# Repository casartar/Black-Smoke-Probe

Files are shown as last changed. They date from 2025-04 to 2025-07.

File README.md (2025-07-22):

# Black Smoke Probe

## Einleitung
Die Black Smoke Probe ist eine Open Source Hardware, die kompatibel ist zur Black Magic Probe v2.1e.

Ich habe den letzten öffentlich zugänglichen [Schaltplan](https://black-magic.org/_downloads/5a984c502435264dc19bc5e08c8b55cd/bmpm_v2_1e_schematic.pdf) genommen und die Micro-USB durch eine USB-C Buchse ersetzt. 

Da die Platine leicht von Hand zu bestücken sein sollte, ist das Layout single sided und einige Bauteile als auch die Diemensions der Platine größer gewählt als beim Original. Diesen Maßnahmen ist die UART zum Opfer gefallen und ist nur noch als Testpoints auf der Bottom Seite verfügbar (Ohne Level-Shifter). 

## Original Firmware
[https://github.com/blackmagic-debug/blackmagic](https://github.com/blackmagic-debug/blackmagic)

## iBOM
[ibom.html](https://html-preview.github.io/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)

## Flashen

### Flashen des Bootloaders
```
st-flash write blackmagic_native_bootloader.bin 0x08000000
```

### Flashen der Applikation
```
dfu-util -d 1d50:6018,:6017 -s 0x08002000:leave -D blackmagic_native_firmware.bin
```

## Testen

[https://github.com/casartar/BlackPillUniversalTester](https://github.com/casartar/BlackPillUniversalTester)

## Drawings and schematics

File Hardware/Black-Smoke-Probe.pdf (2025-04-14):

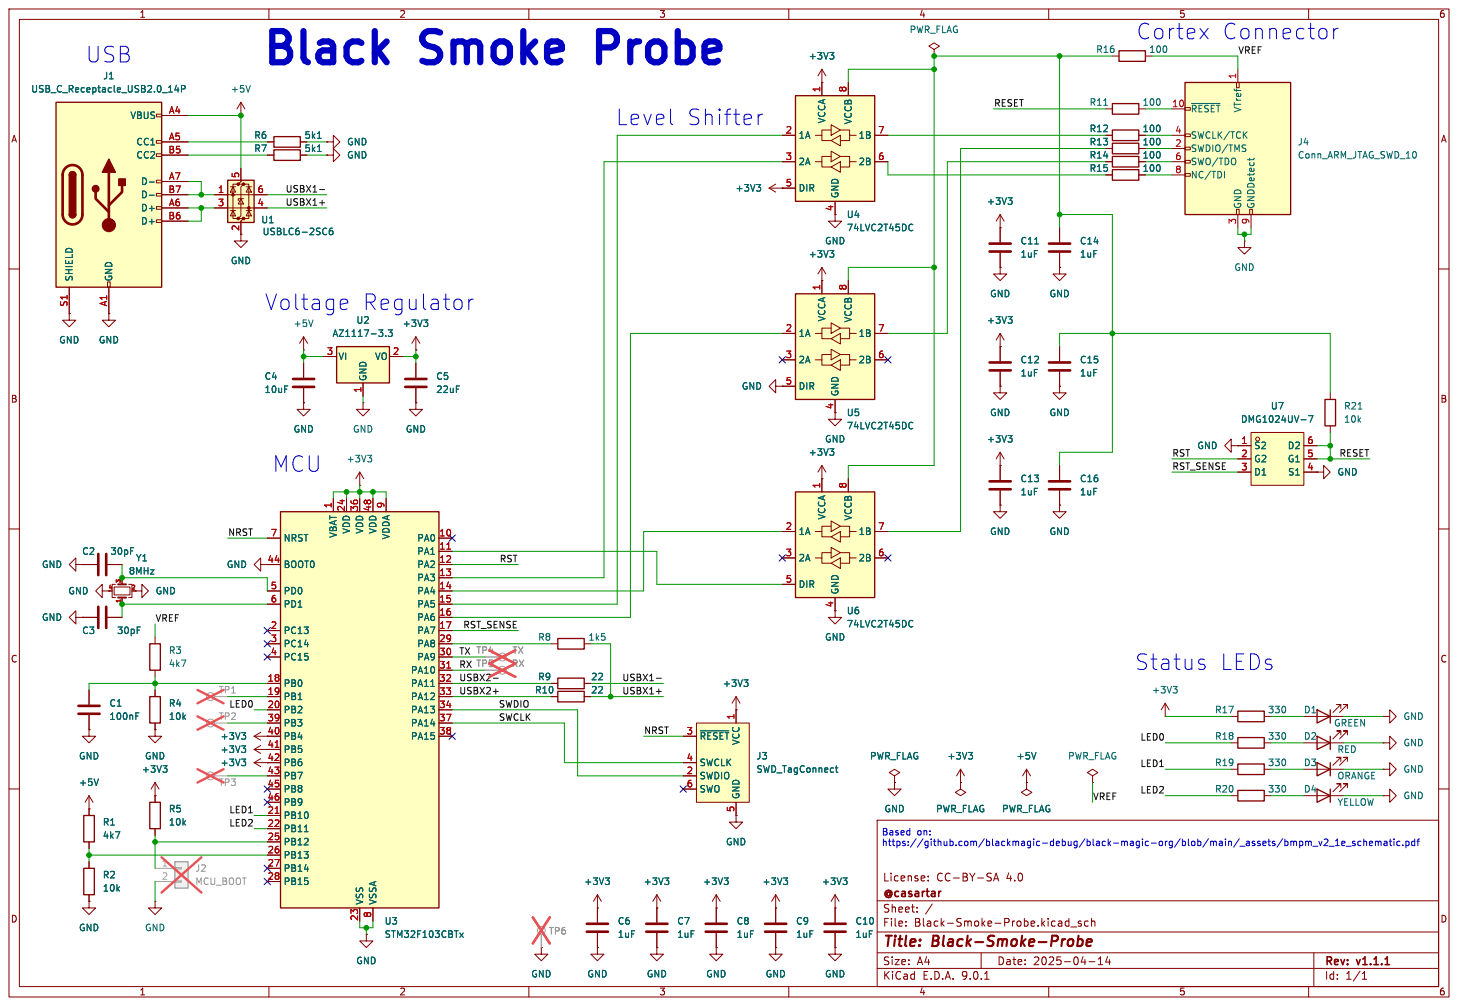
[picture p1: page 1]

3 ~{RESET} 10 SWCLK/TCK 4 SWDIO/TMS 2 SWO/TDO 6 NC/TDI 8

1 VDD 24 VDD 36 VSS 23 VDD 48 VSSA

5 ~{RESET} 3 SWCLK 4 SWDIO 2 SWO 6 R10 22 TP5 RX R9 22 TP4 TX GND

5 ~{RESET} 3 SWCLK 4 SWDIO 2 SWO 6

Based on: https://github.com/blackmagic-debug/black-magic-org/blob/main/_assets/bmpm_v2_1e_schematic.pdf

Id: 1/1 Title: Black-Smoke-Probe

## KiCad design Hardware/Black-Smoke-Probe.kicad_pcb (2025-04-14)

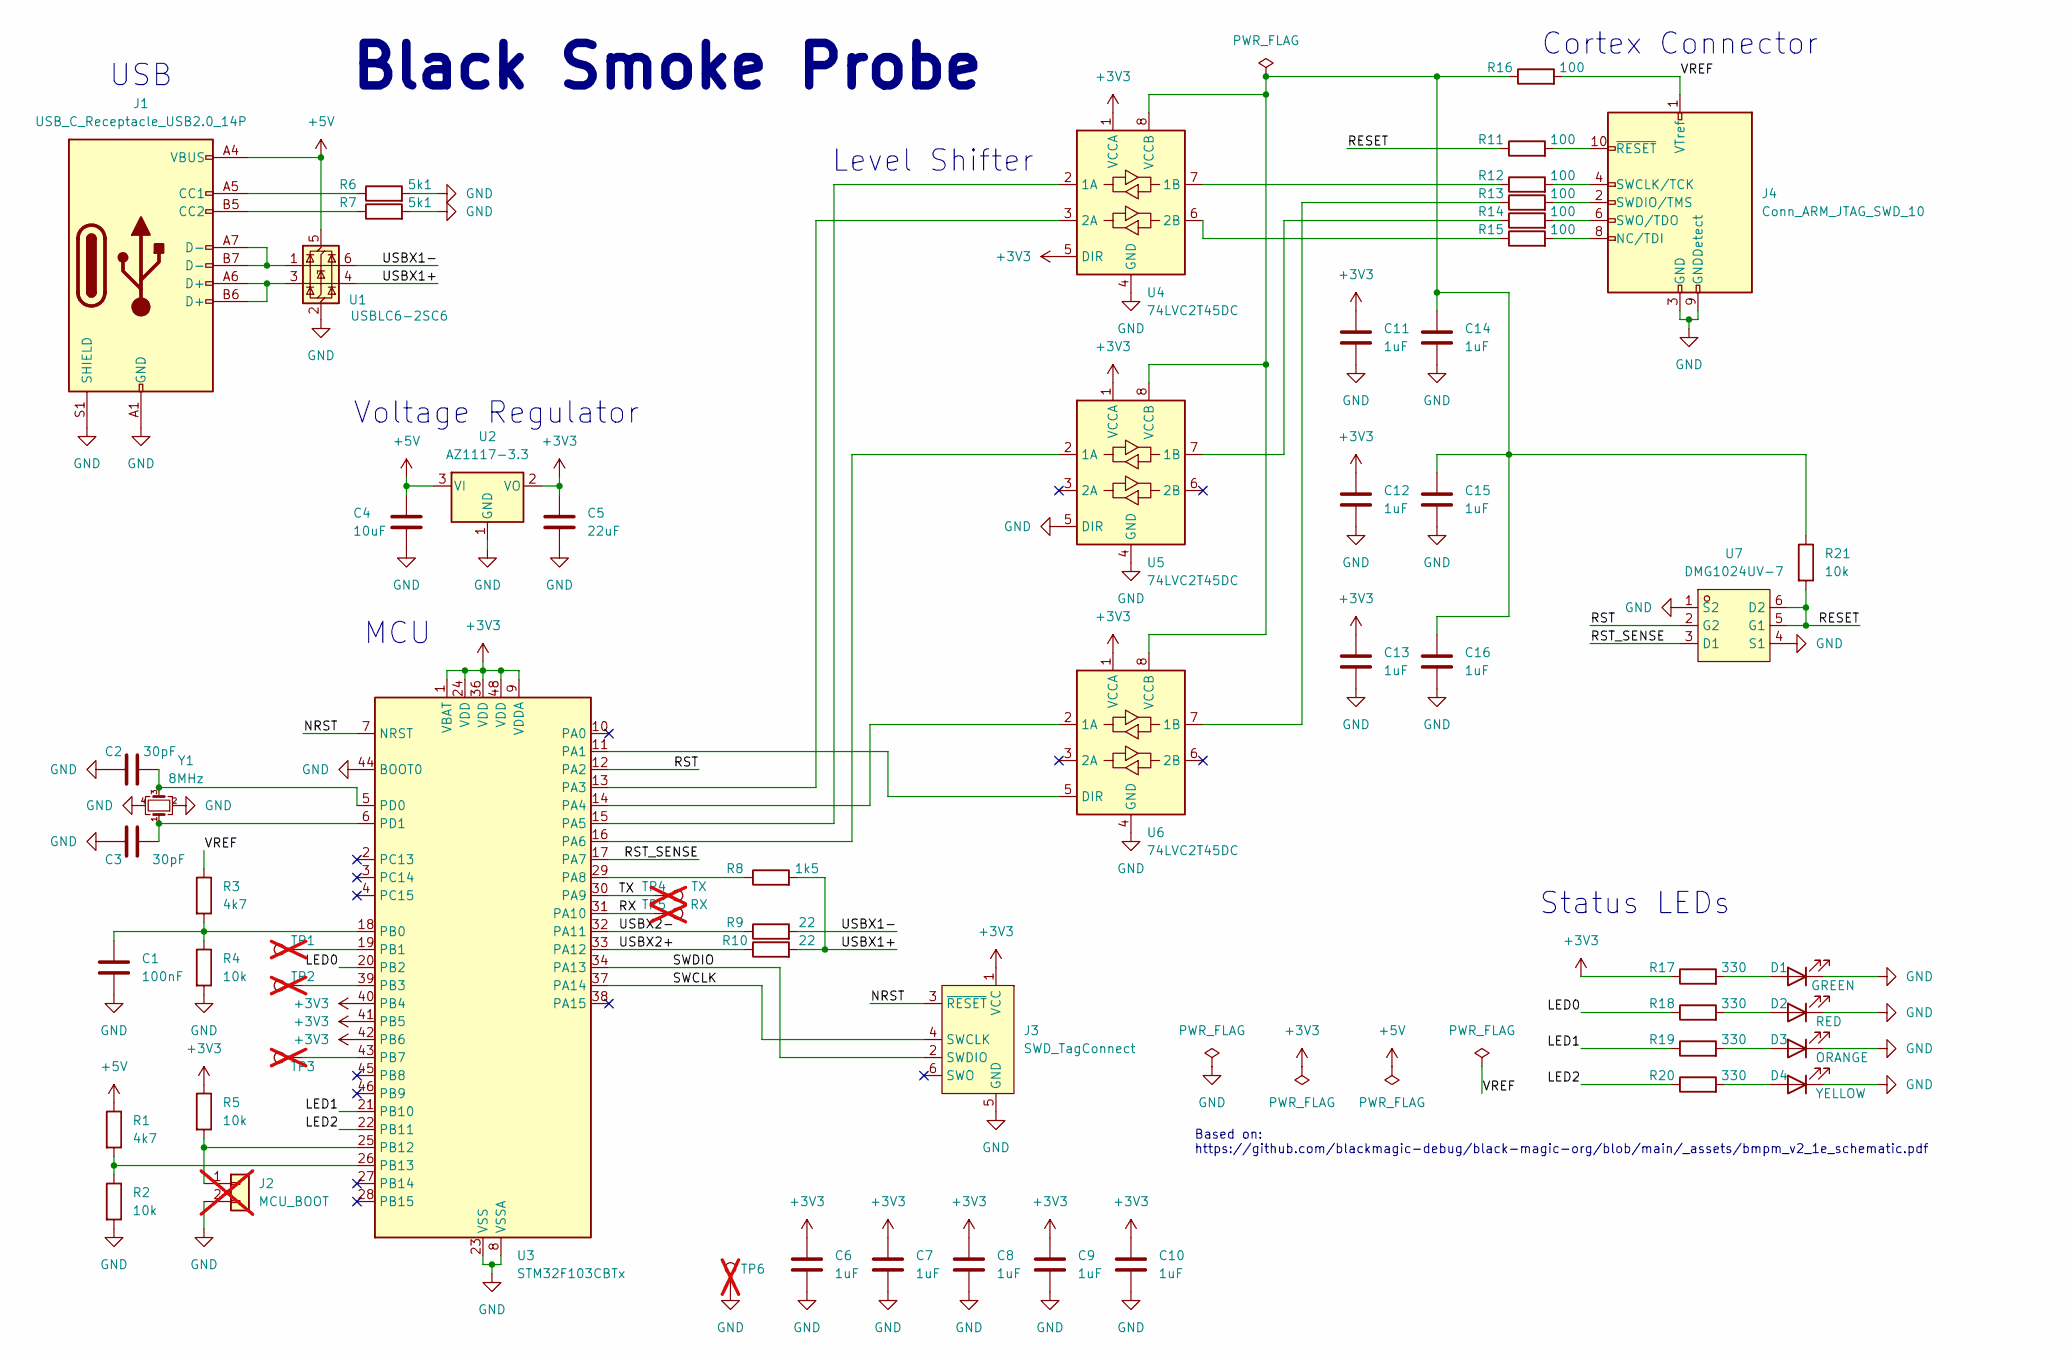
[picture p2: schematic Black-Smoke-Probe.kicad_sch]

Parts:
C1: 100nF; C_0603_1608Metric; LCSC Part C14663
C2, C3: 30pF; C_0603_1608Metric; LCSC Part C1658
C4: 10uF; C_0603_1608Metric; LCSC Part C19702
C5: 22uF; C_0603_1608Metric; LCSC Part C86295
C6, C7, C8, C9, C10, C11, C12, C13, C14, C15, C16: 1uF; C_0603_1608Metric; LCSC Part C15849
D1: GREEN; LED_0603_1608Metric; LCSC Part C12065
D2: RED; LED_0603_1608Metric; LCSC Part C157741
D3: ORANGE; LED_0603_1608Metric; LCSC Part C157740
D4: YELLOW; LED_0603_1608Metric; LCSC Part C160477
J1: USB_C_Receptacle_USB2.0_14P; USB_C_Receptacle_HRO_TYPE-C-31-M-12; LCSC Part C165948
J2: MCU_BOOT; PinHeader_1x02_P2.54mm_Vertical; not fitted
J3: SWD_TagConnect; Tag-Connect_TC2030-IDC-NL_2x03_P1.27mm_Vertical
J4: Conn_ARM_JTAG_SWD_10; PinHeader_2x05_P1.27mm_Vertical_SMD; LCSC Part C42372555
R1, R3: 4k7; R_0603_1608Metric; LCSC Part C105428
R2, R4, R5, R21: 10k; R_0603_1608Metric; LCSC Part C98220
R6, R7: 5k1; R_0603_1608Metric; LCSC Part C105580
R8: 1k5; R_0603_1608Metric; LCSC Part C22843
R9, R10: 22; R_0603_1608Metric; LCSC Part C1203
R11, R12, R13, R14, R15, R16: 100; R_0603_1608Metric; LCSC Part C105588
R17, R18, R19, R20: 330; R_0603_1608Metric; LCSC Part C105881
TP1, TP2, TP3, TP6: TestPoint; TestPoint_Pad_D1.0mm; not fitted
TP4: TX; TestPoint_Pad_D1.0mm; not fitted
TP5: RX; TestPoint_Pad_D1.0mm; not fitted
U1: USBLC6-2SC6; SOT-23-6; LCSC Part C2827654
U2: AZ1117-3.3; SOT-89-3; LCSC Part C460428
U3: STM32F103CBTx; LQFP-48_7x7mm_P0.5mm; LCSC Part C8304
U4, U5, U6: 74LVC2T45DC; VSSOP-8_2.3x2mm_P0.5mm; LCSC Part C15741
U7: DMG1024UV-7; SOT-563-6_L1.6-W1.2-P0.5-LS1.6-BL; LCSC Part C2759893
Y1: 8MHz; Crystal_SMD_3225-4Pin_3.2x2.5mm; LCSC Part C2682775

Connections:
+3V3: C5.1, C6.1, C7.1, C8.1, C9.1, C10.1, C11.1, C12.1, C13.1, J3.1 (VCC), R5.1, R17.1, U2.2 (VO), U3.1 (VBAT), U3.9 (VDDA), U3.24 (VDD), U3.36 (VDD), U3.40 (PB4), U3.41 (PB5), U3.42 (PB6), U3.48 (VDD), U4.1 (VCCA), U4.5 (DIR), U5.1 (VCCA), U6.1 (VCCA)
+5V: C4.1, J1.A4 (VBUS), J1.A9 (VBUS), J1.B4 (VBUS), J1.B9 (VBUS), R1.1, U1.5 (VBUS), U2.3 (VI)
/LED0: R18.1, U3.20 (PB2)
/LED1: R19.1, U3.21 (PB10)
/LED2: R20.1, U3.22 (PB11)
/NRST: J3.3 (~RESET), U3.7 (NRST)
/RESET: R11.1, R21.2, U7.5 (G1), U7.6 (D2)
/RST: U3.12 (PA2), U7.2 (G2)
/RST_SENSE: U3.17 (PA7), U7.3 (D1)
/RX: TP5.1, U3.31 (PA10)
/SWCLK: J3.4 (SWCLK), U3.37 (PA14)
/SWDIO: J3.2 (SWDIO), U3.34 (PA13)
/TX: TP4.1, U3.30 (PA9)
/USBX1+: R8.2, R10.2, U1.4 (I/O2)
/USBX1-: R9.2, U1.6 (I/O1)
/USBX2+: R10.1, U3.33 (PA12)
/USBX2-: R9.1, U3.32 (PA11)
/VREF: J4.1 (VTref), R3.1, R16.2
GND: C1.2, C2.2, C3.1, C4.2, C5.2, C6.2, C7.2, C8.2, C9.2, C10.2, C11.2, C12.2, C13.2, C14.2, C15.2, C16.2, D1.1 (K), D2.1 (K), D3.1 (K), D4.1 (K), J1.A1 (GND), J1.A12 (GND), J1.B1 (GND), J1.B12 (GND), J1.S1 (SHIELD), J2.2, J3.5 (GND), J4.3 (GND), J4.5 (GND), J4.9 (GNDDetect), R2.2, R4.2, R6.2, R7.2, TP6.1, U1.2 (GND), U2.1 (GND), U3.8 (VSSA), U3.23 (VSS), U3.35 (VSS), U3.44 (BOOT0), U3.47 (VSS), U4.4 (GND), U5.4 (GND), U5.5 (DIR), U6.4 (GND), U7.1 (S2), U7.4 (S1), Y1.2, Y1.4
unnamed: D1.2 (A), R17.2
unnamed: D2.2 (A), R18.2
unnamed: D3.2 (A), R19.2
unnamed: D4.2 (A), R20.2
unnamed: J1.A5 (CC1), R6.1
unnamed: J1.B5 (CC2), R7.1
unnamed: J1.A6 (D+), J1.B6 (D+), U1.3 (I/O2)
unnamed: J1.A7 (D-), J1.B7 (D-), U1.1 (I/O1)
unnamed: J2.1, R5.2, U3.25 (PB12)
unnamed: J4.8 (NC/TDI), R15.2
unnamed: J4.4 (SWCLK/TCK), R12.2
unnamed: J4.2 (SWDIO/TMS), R13.2
unnamed: J4.6 (SWO/TDO), R14.2
unnamed: J4.10 (~RESET), R11.2
unnamed: U3.11 (PA1), U6.5 (DIR)
unnamed: U3.13 (PA3), U4.3 (2A)
unnamed: U3.14 (PA4), U6.2 (1A)
unnamed: U3.15 (PA5), U4.2 (1A)
unnamed: U3.16 (PA6), U5.2 (1A)
unnamed: R8.1, U3.29 (PA8)
unnamed: C1.1, R3.2, R4.1, U3.18 (PB0)
unnamed: TP1.1, U3.19 (PB1)
unnamed: TP2.1, U3.39 (PB3)
unnamed: TP3.1, U3.43 (PB7)
unnamed: R1.2, R2.1, U3.26 (PB13)
unnamed: C2.1, U3.5 (PD0), Y1.3
unnamed: C3.2, U3.6 (PD1), Y1.1
unnamed: R12.1, U4.7 (1B)
unnamed: R15.1, U4.6 (2B)
unnamed: C14.1, C15.1, C16.1, R16.1, R21.1, U4.8 (VCCB), U5.8 (VCCB), U6.8 (VCCB)
unnamed: R14.1, U5.7 (1B)
unnamed: R13.1, U6.7 (1B)

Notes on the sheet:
Status LEDs
Based on: https://github.com/blackmagic-debug/black-magic-org/blob/main/_assets/bmpm_v2_1e_schematic.pdf
Cortex Connector
Voltage Regulator
MCU
Level Shifter
Black Smoke Probe
USB

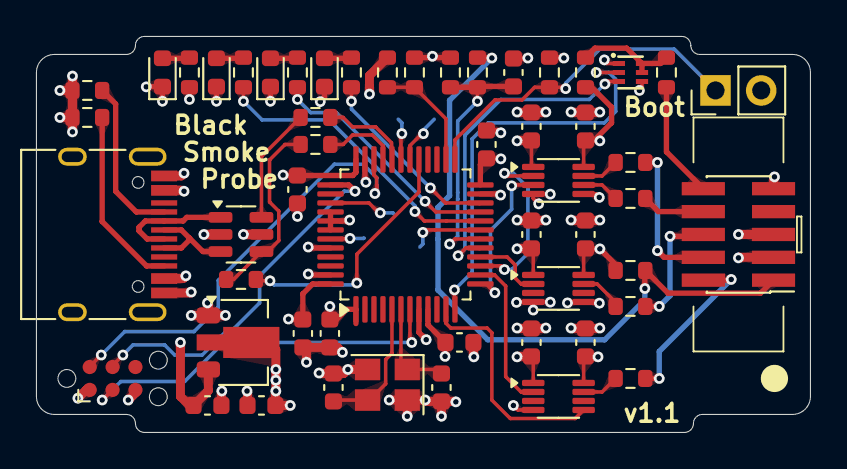
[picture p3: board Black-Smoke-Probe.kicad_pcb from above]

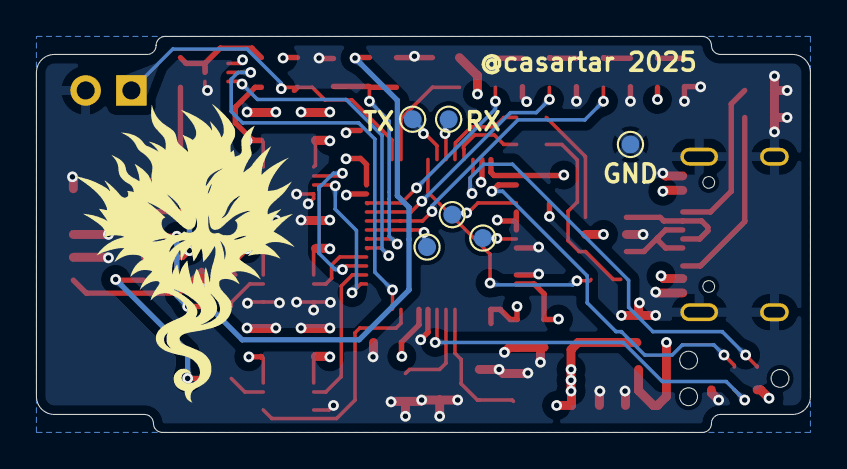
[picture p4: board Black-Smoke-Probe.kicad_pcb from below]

Board: 4 copper layers, 43.0 x 22.0 mm, 59 parts (6 on the bottom side), 51 nets.

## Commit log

2025-03-26 initial commit v1.0
    [Black-Smoke-Probe.kicad_pcb, Black-Smoke-Probe.kicad_sch]
2025-04-08 first changes for v1.1
    - schematic corrections
    - new layout with 4 layer PCB
    [Black-Smoke-Probe.kicad_pcb, Black-Smoke-Probe.kicad_sch]
2025-04-08 bom, schematic, drc corrections and add logo
    [Black-Smoke-Probe.kicad_pcb, Black-Smoke-Probe.kicad_sch]
2025-04-09 remove top gnd plane
    [Black-Smoke-Probe.kicad_pcb]
2025-04-09 add license
    [Black-Smoke-Probe.kicad_sch]
2025-04-11 add schematic pdf
2025-04-14 v1.1.1 changed capacitor from 100nf to 30pf
    [Black-Smoke-Probe.kicad_pcb, Black-Smoke-Probe.kicad_sch]
2025-07-22 change folder structure and update readme
    [Black-Smoke-Probe.kicad_pcb, Black-Smoke-Probe.kicad_sch]

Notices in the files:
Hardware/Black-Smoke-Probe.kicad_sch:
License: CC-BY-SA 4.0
